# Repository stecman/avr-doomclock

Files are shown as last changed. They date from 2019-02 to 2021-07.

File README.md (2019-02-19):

# Tiny GPS Clock

This is a `hh:mm:ss` clock that runs from the time contained in NMEA RMC sentences.
The code is targeted at an Atmel ATTiny13A.

Notes:

- As the target microcontroller doesn't have enough RAM to store a full NMEA sentence,
this project uses a custom parser that only reads RMC ("Recommended Minimum") sentences from a UART
and extracts the time from that (see`nmea.c`).

- The ATTiny13A lacks SPI and UART peripherals, so these are implemented in software.

Schematic and construction details can be found on [this project's hackaday.io page](https://hackaday.io/project/163826-gps-wall-clock).

## Building and flashing

The `avr-gcc` toolchain is required to build, but there are no other external dependencies.

```sh
# Build
make

# Flash with programmer configured in Makefile
make flash
```

## Testing

The simple test suite for NMEA RMC sentence decoding can be run manually with:

```sh
make test
```

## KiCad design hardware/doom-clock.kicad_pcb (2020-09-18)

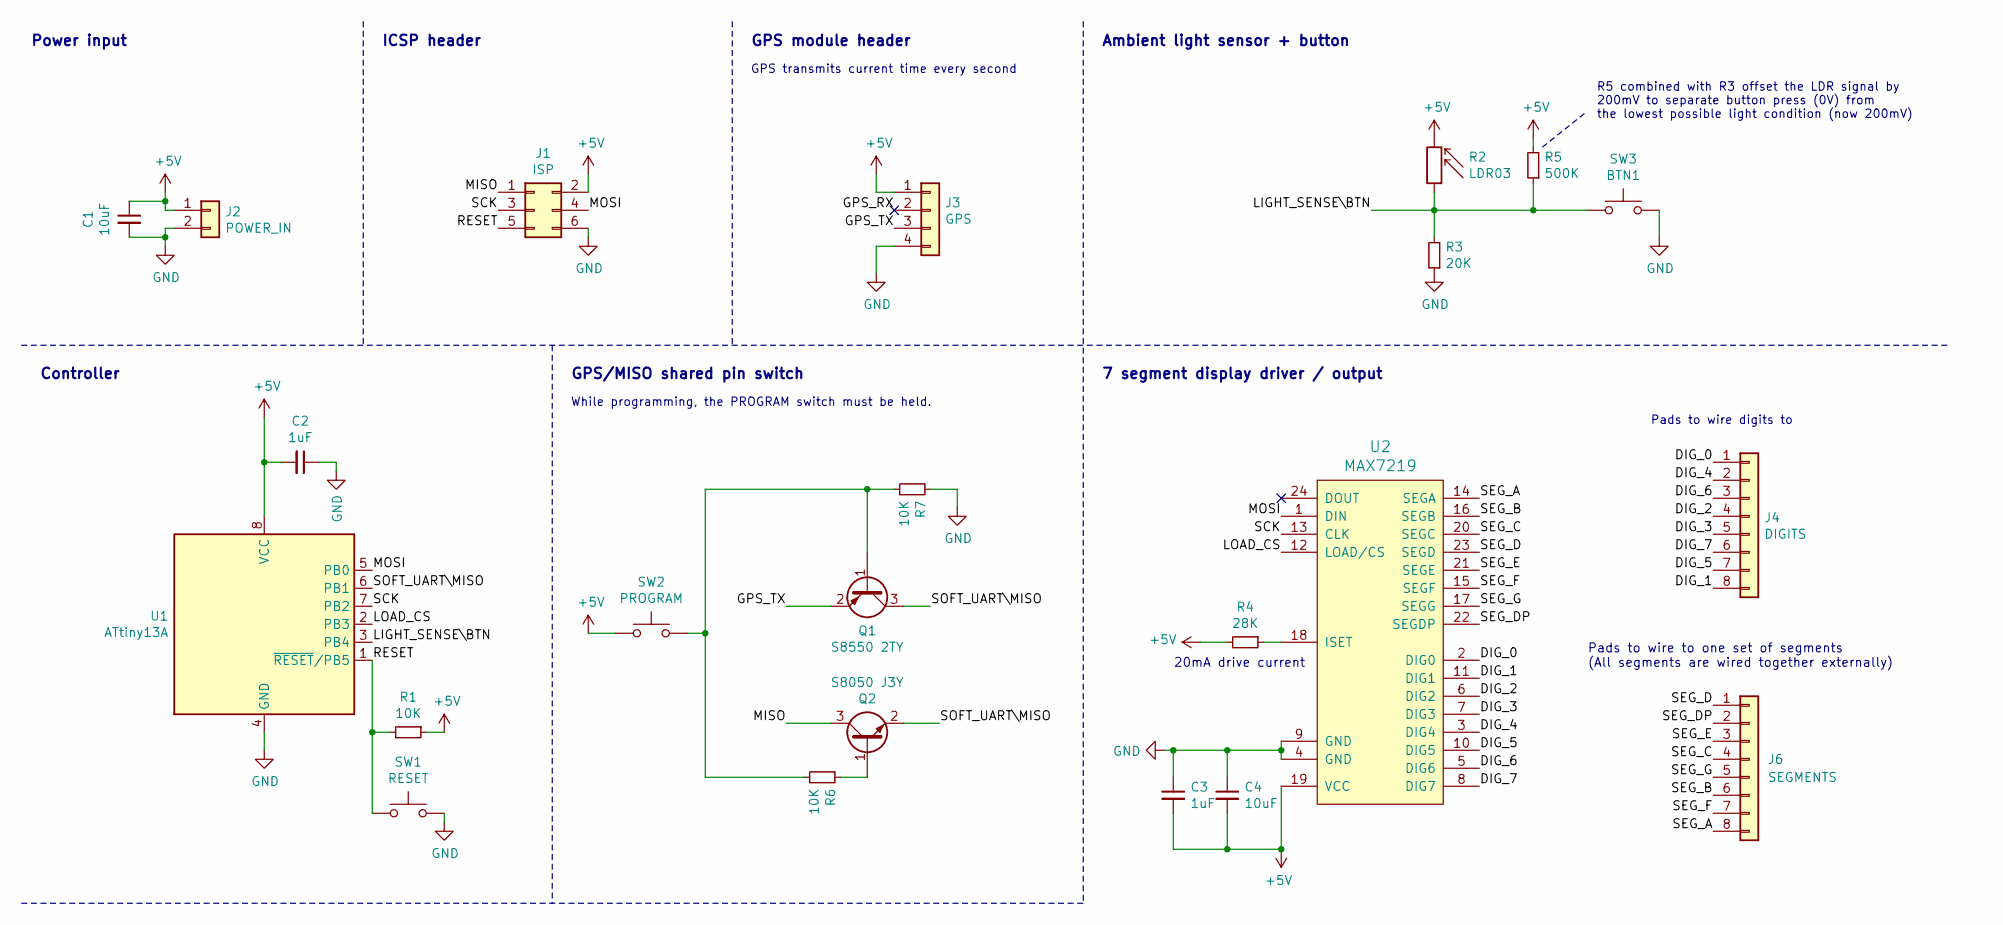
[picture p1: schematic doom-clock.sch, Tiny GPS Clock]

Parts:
C1, C4: 10uF; C_1206_3216Metric_Pad1.42x1.75mm_HandSolder
C2, C3: 1uF; C_1206_3216Metric_Pad1.42x1.75mm_HandSolder
J1: ISP; PinSocket_1x06_P1.27mm_Vertical
J2: POWER_IN; PinHeader_1x02_P2.54mm_Vertical
J3: GPS; PinHeader_1x04_P2.54mm_Vertical
J4: DIGITS; PinHeader_1x08_P2.54mm_Vertical
J6: SEGMENTS; PinSocket_1x08_P2.54mm_Vertical
Q1: S8550 2TY; SOT-23
Q2: S8050 J3Y; SOT-23
R1, R6, R7: 10K; R_1206_3216Metric_Pad1.42x1.75mm_HandSolder
R2: LDR03; R_LDR_5.2x5.2mm_P3.5mm_Horizontal
R3: 20K; R_1206_3216Metric_Pad1.42x1.75mm_HandSolder
R4: 28K; R_1206_3216Metric_Pad1.42x1.75mm_HandSolder
R5: 500K; R_1206_3216Metric_Pad1.42x1.75mm_HandSolder
SW1: RESET; SW_SPST_FSMSM
SW2: PROGRAM; SW_SPST_FSMSM
SW3: BTN1; SW_SPST_FSMSM
U1: ATtiny13A; SOIJ-8_SOIC-8
U2: MAX7219; SOP-24

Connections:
+5V: C1.1, C2.2, C3.2, C4.2, J1.2, J2.1, J3.1, R1.1, R2.2, R4.2, R5.2, SW2.1, U1.8 (VCC), U2.19 (VCC)
/DIG_0: J4.1, U2.2 (DIG0)
/DIG_1: J4.8, U2.11 (DIG1)
/DIG_2: J4.4, U2.6 (DIG2)
/DIG_3: J4.5, U2.7 (DIG3)
/DIG_4: J4.2, U2.3 (DIG4)
/DIG_5: J4.7, U2.10 (DIG5)
/DIG_6: J4.3, U2.5 (DIG6)
/DIG_7: J4.6, U2.8 (DIG7)
/GPS_TX: J3.3, Q1.2 (E)
/LIGHT_SENSE\BTN: R2.1, R3.2, R5.1, SW3.1, U1.3 (PB4)
/LOAD_CS: U1.2 (PB3), U2.12 (LOAD/CS)
/MISO: J1.1, Q2.3 (C)
/MOSI: J1.4, U1.5 (PB0), U2.1 (DIN)
/RESET: J1.5, R1.2, SW1.1, U1.1 (~RESET~/PB5)
/SCK: J1.3, U1.7 (PB2), U2.13 (CLK)
/SEG_A: J6.8, U2.14 (SEGA)
/SEG_B: J6.6, U2.16 (SEGB)
/SEG_C: J6.4, U2.20 (SEGC)
/SEG_D: J6.1, U2.23 (SEGD)
/SEG_DP: J6.2, U2.22 (SEGDP)
/SEG_E: J6.3, U2.21 (SEGE)
/SEG_F: J6.7, U2.15 (SEGF)
/SEG_G: J6.5, U2.17 (SEGG)
/SOFT_UART\MISO: Q1.3 (C), Q2.2 (E), U1.6 (PB1)
GND: C1.2, C2.1, C3.1, C4.1, J1.6, J2.2, J3.4, R3.1, R7.2, SW1.2, SW3.2, U1.4 (GND), U2.4 (GND), U2.9 (GND)
unnamed: Q1.1 (B), R6.1, R7.1, SW2.2
unnamed: Q2.1 (B), R6.2
unnamed: R4.1, U2.18 (ISET)

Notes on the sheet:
20mA drive current
Pads to wire to one set of segments (All segments are wired together externally)
Power input
ICSP header
Controller
GPS module header
GPS/MISO shared pin switch
Ambient light sensor + button
7 segment display driver / output
R5 combined with R3 offset the LDR signal by 200mV to separate button press (0V) from the lowest possible light condition (now 200mV)
While programming, the PROGRAM switch must be held.
GPS transmits current time every second
Pads to wire digits to

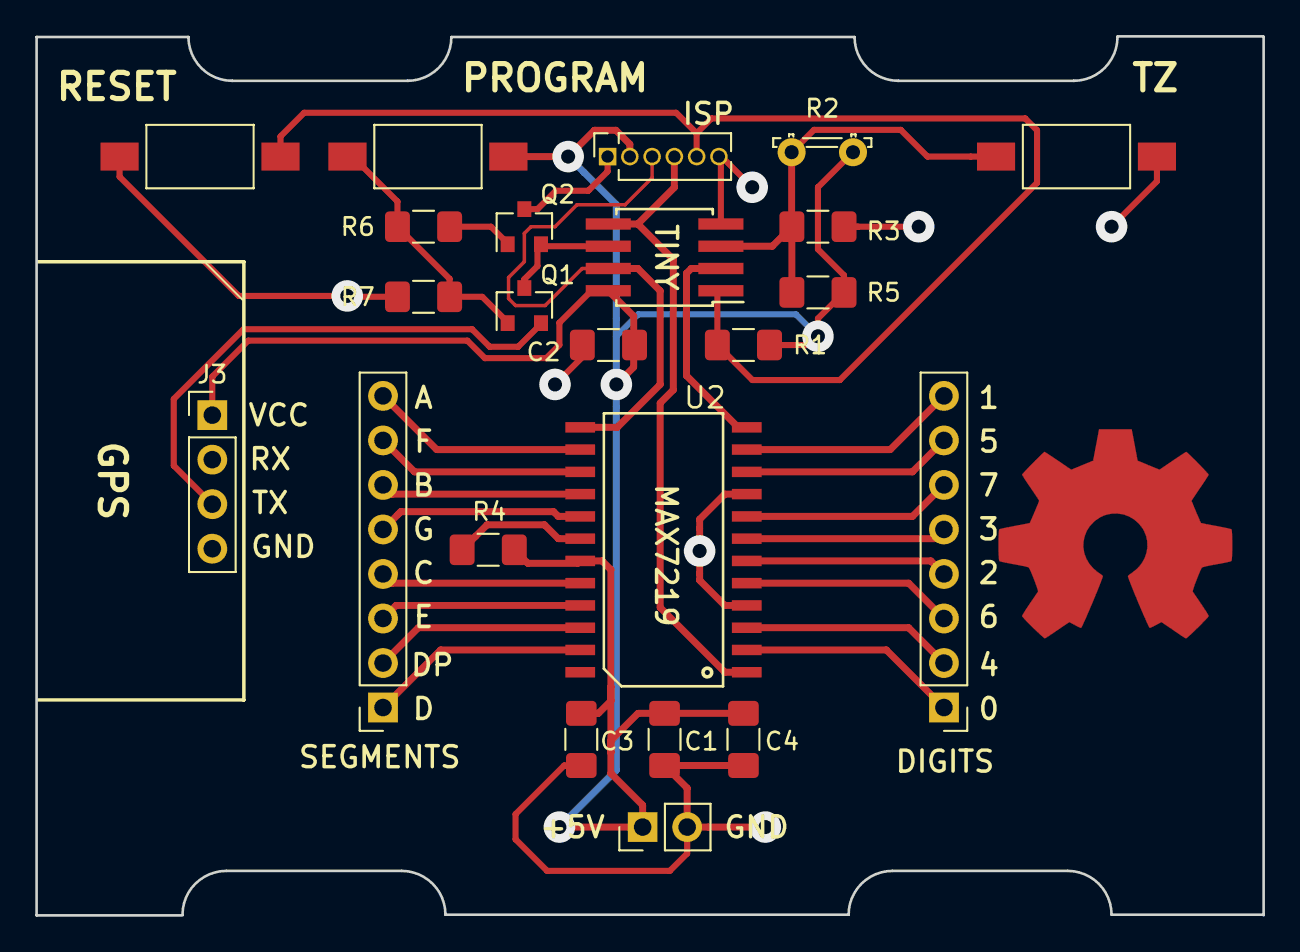
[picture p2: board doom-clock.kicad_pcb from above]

Board: 2 copper layers, 70.0 x 50.1 mm, 23 parts (0 on the bottom side), 29 nets.

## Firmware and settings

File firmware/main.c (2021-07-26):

#include <avr/io.h>
#include <avr/interrupt.h>
#include <util/delay.h>
#include <stdbool.h>

// Include sources directly so the compiler can optimise everything together
// This saves a significant amount of code space
#include "softuart.c"
#include "nmea.c"

#define PIN_MOSI PB0
#define PIN_SCK PB2
#define PIN_LOAD PB3
#define PIN_LIGHT_SENSE PB4

#define EEPROM_TIMEZONE_ADDR 0
#define kNumDigits 6

static int8_t _timezoneOffset = 0;
static GpsTime _gpsTime = {0, 0, 0};

static uint8_t _display_buf[kNumDigits];

static inline void setup_pins()
{
    // Load/CS pin is active low - initialise as high
    PORTB = _BV(PIN_LOAD);

    // MAX7219 pins as output
    // Soft UART and LDR are inputs by omission
    DDRB = _BV(PIN_MOSI) | _BV(PIN_SCK) | _BV(PIN_LOAD);
}

static inline void setup_adc()
{
    // Select PB4 (PIN_LIGHT_SENSE) in the ADC multiplexer
    // Put the significant 8-bits in the upper register as we only want to read that
    ADMUX = _BV(MUX1) | _BV(ADLAR);

    // Enable free-running ADC conversions with largest prescaler
    ADCSRA = _BV(ADATE) | _BV(ADEN) | _BV(ADSC)
        | _BV(ADPS0) | _BV(ADPS1) | _BV(ADPS2);
}

static inline void setup_timer()
{
    // Run TIM0 with 1024 prescaler
    TCCR0B = _BV(CS00) | _BV(CS02);
}

__attribute__ ((unused))
static void eeprom_wait_for_write()
{
    while(EECR & (1<<EEPE));
}

static void unchecked_eeprom_write(uint8_t address, uint8_t data)
{
    // Note: this doesn't wait for completion of any previous write
    // This is a code size optimisation as we only write a single byte infrequently

    // Set Programming mode
    EECR = (0 << EEPM1) | (0 >> EEPM0);

    // Set up address and data registers
    EEARL = address;
    EEDR = data;

    // Write logical one to EEMPE
    EECR |= (1 << EEMPE);
    // Start eeprom write by setting EEPE
    EECR |= (1 << EEPE);
}

static uint8_t unchecked_eeprom_read(uint8_t address)
{
    // Note: this doesn't wait for completion of any previous write
    // This is a code size optimisation as we only read at start-up, before any writes

    // Set up address register
    EEARL = address;

    // Start eeprom read by writing EERE
    EECR |= (1 << EERE);

    // Return data from data register
    return EEDR;
}

/**
 * Clock out a command and data pair to the MAX7219 (SPI-like)
 */
static void spi_send_16(uint16_t value)
{
    // Clock out 8 bits, MSB first
    for (uint8_t i = 16; i != 0; --i) {
        // Bring the clock low
        PORTB &= ~_BV(PIN_SCK);

        // Set output to 0
        PORTB &= ~_BV(PIN_MOSI);

        // Set output to 1 if this bit is set
        if (value & 0x8000) {
            PORTB |= _BV(PIN_MOSI);
        }

        // Bring clock high to send bit
        PORTB |= _BV(PIN_SCK);

        // Next bit
        value <<= 1;
    }
}

/**
 * Write to a register on the MAX7219
 */
static void max7219_cmd(uint8_t address, uint8_t data)
{
    // Select chip (active low)
    PORTB &= ~_BV(PIN_LOAD);

    // Clock out address and data as a combined word for code size savings
    spi_send_16((address << 8) | data);

    // Pull chip select high to latch data
    PORTB |= _BV(PIN_LOAD);
}

/**
 * Configure the MAX7219 for use
 */
static void max7219_init()
{
    // Set scan mode to 6 digits
    max7219_cmd(0x0B, kNumDigits);

    // Disable test mode
    max7219_cmd(0x0F, 0);

    // Enable binary decode mode
    max7219_cmd(0x09, 0xFF);

    // Enable display
    max7219_cmd(0x0C, 1);
}

/**
 * Modify the passed time with the current timezone offset
 */
static void apply_timezone_offset(GpsTime* now)
{
    // Adjust hour for timezone
    int8_t hour = now->hour;
    hour += _timezoneOffset;

    if (hour > 23) {
        hour -= 24;
    } else if (hour < 0) {
        hour += 24;
    }

    now->hour = hour;
}


static inline void set_display_pending_flag()
{
    // Re-purpose an unused register for single instruction set/clear
    // The reset pin isn't used as I/O, so this changing its registers has no effect
    DDRB |= _BV(PB5);
}

static inline uint8_t is_display_pending()
{
    // See set_display_pending_flag for what's going on here
    return DDRB & _BV(PB5);
}

static inline void clear_display_pending_flag()
{
    // See set_display_pending_flag for what's going on here
    DDRB &= ~_BV(PB5);
}


static inline void set_timepulse_seen_flag()
{
    // Re-purpose an unused register for single instruction set/clear
    // This "input buffer disable register" bit isn't functional as PB0 is always an output
    DIDR0 |= _BV(AIN0D);
}

static inline uint8_t has_seen_timepulse()
{
    // See set_timepulse_seen_flag for what's going on here
    return DIDR0 & _BV(AIN0D);
}

static inline void clear_timepulse_seen_flag()
{
    // See set_timepulse_seen_flag for what's going on here
    DIDR0 &= ~_BV(AIN0D);
}


static inline void display_buffer_set(uint8_t index, uint8_t value)
{
    _display_buf[index] = value;
}

/**
 * Send the current time to the MAX7219 as 6 BCD digits
 */
static void display_buffer_update(GpsTime* now)
{
    // Send time to display
    uint8_t digit = 0;

    for (int8_t i = 0; i < 3; ++i) {

        // Manually digit into tens and ones columns
        // This saves 25 bytes vs. using the divide and modulo operators.
        uint8_t ones = ((uint8_t*) now)[i];
        uint8_t tens = 0;

        while (ones >= 10) {
            ones -= 10;
            ++tens;
        }

        display_buffer_set(digit++, tens);
        display_buffer_set(digit++, ones);
    }
}

static void display_buffer_send()
{
    for (int8_t i = kNumDigits; i != 0; --i) {
        // Send buffer values to 1-indexed digit addresses
        max7219_cmd(i, _display_buf[i-1]);
    }
}

/**
 * Set all digits on the display to a value with no illuminated segments
 */
static void display_clear()
{
    // Reverse loop to save an instruction as the order doesn't matter
    for (int8_t i = kNumDigits - 1; i >= 0; --i) {
        _display_buf[i] = 0x7F;
    }
}

static void display_no_signal()
{
    static uint8_t waitIndicator = 0;

    display_clear();

    // Turn on the decimal point on one digit
    display_buffer_set(waitIndicator, 0x8F);

    ++waitIndicator;
    if (waitIndicator == kNumDigits) {
        waitIndicator = 0;
    }
}

static void display_error_code(uint8_t code)
{
    display_clear();

    // Display error code
    display_buffer_set(0, 11 /* E */);
    display_buffer_set(1, code);
}

static void display_timezone()
{
    display_clear();

    uint8_t value;

    // Put sign of timezone in the hours column
    if (_timezoneOffset < 0) {
        display_buffer_set(1, 10 /* - */);
        value = _timezoneOffset * -1;
    } else {
        display_buffer_set(1, 14 /* P */);
        value = _timezoneOffset;
    }

    // Split value into tens and ones columns manually to save code size
    uint8_t ones = value;
    uint8_t tens = 0;

    while (ones >= 10) {
        ones -= 10;
        ++tens;
    }

    // Put number in the middle
    display_buffer_set(2, tens);
    display_buffer_set(3, ones);
}

static void increment_timezone()
{
    ++_timezoneOffset;

    if (_timezoneOffset > 13) {
        _timezoneOffset = -12;
    }
}

void increment_time(GpsTime* tim)
{
    ++tim->second;

    if (tim->second == 60) {
        tim->second = 0;
        ++tim->minute;
    }

    if (tim->minute == 60) {
        tim->minute = 0;
        ++tim->hour;
    }

    if (tim->hour == 24) {
        tim->hour = 0;
    }
}

static void restore_timezone()
{
    const int8_t timezone = unchecked_eeprom_read(EEPROM_TIMEZONE_ADDR);

    // Restore if the value read from eeprom looks like a timezone
    if (timezone >= -12 && timezone <= 13) {
        _timezoneOffset = timezone;
    }
}

static void display_adjust_brightness(const uint8_t reading)
{
    // Map of brightness (index) to minimum ADC reading to trigger
    // Note the 200mV offset reads as around 10 with this configuration
    static const __flash uint8_t brightnessTable[] = {
        30, // 9%  duty cycle
        40, // 15% duty cycle
        50, // 21% duty cycle
        65, // 28% duty cycle
        80, // 34% duty cycle
        95, // 40% duty cycle
        110, // 46% duty cycle
        125, // 53% duty cycle
        140, // 59% duty cycle
        155, // 65% duty cycle
        170, // 71% duty cycle
        185, // 78% duty cycle
        200, // 84% duty cycle
        215, // 90% duty cycle
        230, // 96% duty cycle
    };

    // State to obtain an average of LDR readings
    // The size of this array should  be a power of two
    static uint8_t averageBuffer[16] = {};
    static uint8_t writeIndex = 0;
    static uint16_t runningTotal = 0;

    // Adjust running total with the new value
    runningTotal -= averageBuffer[writeIndex];
    runningTotal += reading;

    // Append new reading
    averageBuffer[writeIndex] = reading;
    writeIndex = (writeIndex + 1) % sizeof(averageBuffer);

    const uint8_t average = runningTotal/sizeof(averageBuffer);

    uint8_t intensity = 0;
    while (intensity < sizeof(brightnessTable) && brightnessTable[intensity] < average) {
        ++intensity;
    }

    // Set brightness
    max7219_cmd(0x0A, intensity);
}

static bool wait_for_timepulse()
{
    // Switch LOAD/CS pin to input with pull-up
    // The timepulse signal is wired to pull this line low
    DDRB &= ~_BV(PIN_LOAD);

    // Clear pin change flag
    GIFR |= _BV(PCIF);

    // Wait for a UART or Timepulse to change - whichever comes first
    while ((GIFR & _BV(PCIF)) == 0);

    // Check if the timepulse caused the pin change flag
    bool is_timepulse = (PINB & _BV(PIN_LOAD)) == 0;

    // Set LOAD/CS back to output idling high
    DDRB |= _BV(PIN_LOAD);

    return is_timepulse;
}

static inline bool timer_has_overflowed()
{
    return TIFR0 & _BV(TOV0);
}

static inline void timer_reset_overflow()
{
    TIFR0 = 0xFF; // Clear all TIM0 interrupt flags
}

int main(void)
{
    // Flag state changes on the UART and Timepulse pins
    // Interrupts aren't used, but the interrupt flags are read
    PCMSK = _BV(PIN_SOFT_RX) | _BV(PIN_LOAD);

    setup_pins();
    setup_adc();
    setup_timer();

    max7219_init();

    restore_timezone();

    while (true) {

        // Update brightness if the timer has overflowed
        if (timer_has_overflowed()) {
            timer_reset_overflow();

            const uint8_t reading = ADCH;
            uint8_t numReads = 0;

            // The 200mV offset prevents the LDR output dropping below around 10 in an 8-bit reading
            // When the button is pressed the reading should drop to zero.
            const uint8_t buttonThreshold = 8;

            if (reading < buttonThreshold) {
                const int8_t oldTimezone = _timezoneOffset;

                while (ADCH < buttonThreshold) {
                    ++numReads;

                    // Require the reading to stay below the threshold for a series of readings
                    // (During real world use the ADC reading was occasionally dipping below the
                    // threshold without a button press, causing the timezone to increment unexpectedly.
                    if (numReads <= 15) {
                        while (!timer_has_overflowed()); // Delay for ~27ms
                        timer_reset_overflow();
                        continue;
                    }

                    // Reset period counter
                    numReads = 0;

                    // Update timezone
                    increment_timezone();
                    display_timezone();
                    display_buffer_send();
                }

                // Persist the timezone if it was changed
                if (oldTimezone != _timezoneOffset) {
                    unchecked_eeprom_write(EEPROM_TIMEZONE_ADDR, _timezoneOffset);
                }

            } else {
                // Update the display brightness for the ambient light level
                display_adjust_brightness(reading);
            }
        }

        // Wait for timepulse or UART message
        if (wait_for_timepulse()) {
            // Saw a timepulse signal - update the display immediately
            display_buffer_send();

            set_timepulse_seen_flag();
            clear_display_pending_flag();
        }

        // Wait for a line of text from the GPS unit
        GpsReadStatus status = gps_read_time(&_gpsTime);

        // Handle the processed message from the GPS module
        // This is done last as it blocks to sync with the timepulse signal
        switch (status) {
            case kGPS_Success: {

                // Update the display with the new parsed time
                apply_timezone_offset(&_gpsTime);

                if (is_display_pending()) {
                    // Display was pending but we saw another RMC message
                    // This means a timepulse was expected but didn't happen
                    clear_timepulse_seen_flag();
                    clear_display_pending_flag();
                }

                if (has_seen_timepulse()) {
                    // If preparing the display for the next second, the time needs to be incremented
                    increment_time(&_gpsTime);
                }

                display_buffer_update(&_gpsTime);

                if (has_seen_timepulse()) {
                    // Don't update the display yet - wait for the next timepulse
                    set_display_pending_flag();
                    continue;

                } else {

                    // Flag that display is not synced to timepulse by illuminating the last decimal point
                    _display_buf[kNumDigits - 1] |= 0x80;
                    break;
                }
            }

            case kGPS_NoMatch:
                // Ignore partial and unknown sentences
                continue;

            case kGPS_NoSignal:
                // Walk the decimal point across the display to indicate activity
                display_no_signal();
                break;

            case kGPS_InvalidChecksum:
                display_error_code(1);
                break;

            case kGPS_BadFormat:
                // This state is returned if the UART line isn't pulled high (ie. GPS unplugged)
                display_error_code(2);
                break;
        }

        // Push buffer to the display
        display_buffer_send();
    }
}

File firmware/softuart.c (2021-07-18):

#include "softuart.h"

#include <avr/io.h>
#include <util/delay.h>

// Number of microseconds for a 0.5 bit delay at the desired baud rate
// Calculated as ((1/BPS)/0.000001)/2
#define UART_DELAY_US 49 // ~9600 baud

/**
 * Read a single byte transmitted by the GPS
 */
AVRSTATIC uint8_t uart_read_byte()
{
    uint8_t data = 0x0;

    // Wait for line to go low (start bit)
    while ((PINB & _BV(PIN_SOFT_RX)) != 0);

    // 0.5 bit delay
    _delay_us(UART_DELAY_US);

    // Shift 8 data bits + 1 stop bit at the baud-rate determined by UART_DELAY_MS
    uint8_t bit = 9;
    do {
        --bit;

        // 1 bit delay
        _delay_us(UART_DELAY_US);
        _delay_us(UART_DELAY_US);

        // If this is the stop-bit, don't try to store the value
        if (bit == 0) {
            break;
        }

        // Shift to make room for next bit (reading most-significant bit first)
        data >>= 1;

        if ((PINB & _BV(PIN_SOFT_RX)) != 0) {
            data |= 0x80;
        }
    } while (bit != 0);

    return data;
}

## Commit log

2019-02-04 Fix digit decoding (late-night off math error)
    The display was counting to 11 instead of 10 ...37, 38, 39, 3-, 41, 42...
    [main.c]
2019-02-10 Fix wait indicator not wrapping at digit count
    [main.c]
2019-02-12 Add automatic display brightness based on ambient light level
    This adds code to read the LDR and set brightness smoothly. This may be completely
    overkill, but I'll see how it performs with real use. The problem could be solved
    with less program space using a single threshold with hysteresis to switch between
    "day" and "night" modes.
    I suspect flickering brightness might be an issue with this, which means it would
    need hysteresis anyway. With this chnage the code is now 966 bytes, so something
    might need to be compacted or removed to make room for the timezone button handling.
    [main.c]
2019-02-12 Make small optimisations to free a little program space
    This change-set takes the program size from 966 bytes to 920 bytes, freeing up
    just 4.4% of the total program space.
    - hex2int doesn't need to deal with lowercase characters. Forcing this loop
    to unroll saves 10 bytes. Clarified the code a little here too.
    - Removed null terminator from GPRMC string as it's not used (saves 2 bytes)
    - Removed initial brightness setting from max7219_init (saves 6 bytes):
    Intensity defaults to the minimum value on MAX721 power-up, which isn't a
    problem. Brightness is set correctly when `display_adjust_brightness() is
    eventually called.
    - Removed initial display_no_signal() call as the display w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
    [main.c]
2019-02-12 Reduce compiled size of uart_read_byte function by 18 bytes
    - Half-bit delay is now 49uS as this generates a fewer instructions for the
    configured clock frequency (no padding with nops)
    - Packed stopbit delay into loop to avoid two inlined _delay_us calls.
    This makes the size of this routine on-par with AVR ASM implementations
    I've seen around.
    [softuart.c]
2019-02-19 Improve the test output to abort on failure and use fancy colours
    This also adds a requirement for the tests to run successfully before the
    code will be flashed to a device.
    I really didn't need to do this, but it was a bit of fun.
2019-05-09 Fix negative timezone not handled correctly during display
    DateTime.hour is unsigned, so a negative timezone was displaying
    60-something instead of the correct adjusted hour.
    [main.c]
2019-05-09 Try to avoid timezone changing occassionally without button press
    The timezone has skipped forward 1-2 hours a few times in the last month.
    Something (maybe power glitches while it's already very dark) is causing
    the ADC reading to drop below the button-press threshold for one reading,
    which is advancing the timezone.
    This changes the logic to advance the timezone at the end of the 500ms
    period, requiring 5 readings 100ms apart to register as button presses.
    This should stop any momentary glitches in power or the ADC from causing
    an unwanted timezone change.
    [main.c]
2020-02-15 Reduce code size by 44 bytes to make room for timezone saving code
    This takes the compiled binary size from 994 to 950 bytes in preparation
    for adding code to persist the selected timezone in eeprom.
    Changes in order of most to least space saving:
    - Consolidated display clearing into a single function to save 30 bytes.
    Clearing was performed selectively in few different places which wasted
    quite a bit of code space. The refactored code ended up simpler as a bonus.
    - Dropped date parsing from the GPS decoding to save 14 bytes as
    day/month/year values aren't used in the firmware currently. This has
    been blocked out using an ifdef as the tests still parse dates and I
    didn't want to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
    [main.c]
2020-02-15 Move time mutation out of display_update() for grok-ability
    Coming back to this code after 9 months, I was irked by the display_update()
    mutating the time each call. This isn't technically a problem as the
    function is only called once after reading the time from the GPS, but
    it seems clearer to separate the application of timezone offset to the
    updating of digits on the display.
    This change doesn't affect binary size.
    [main.c]
2020-02-15 Store the last used timezone in eeprom and restore during power-on
    It's been bothering me that the clock doesn't remember its timezone as
    I've needed to unplug it a few times recently. I'm reluctant to unplug
    it currently as I need to take the clock off the wall each time to set
    the timezone again.
    [main.c]
2020-02-15 Fix timezone restored from eeprom typed as unsigned with bad comparison logic
    Fixes dumb late-night mistakes in the implementation
    [main.c]
2020-02-15 Free up an additional 8 bytes for saved timezone validation fix. This brings the code size from 1032 bytes in the previous commit to 1024 bytes (exactly 100% flash usage).
    [main.c]
2020-09-18 Add Kicad schematic and layout
    I'd recommend not using the layout included here as it's pretty gross.
    Best to create your own layout from the schematic.
    [doom-clock.kicad_pcb, doom-clock.sch]
2021-03-20 Add additional test for expected no signal case
2021-03-20 Remove redundant multiplication from manually unrolled loop
    This doesn't change the code size as GCC was smart enough to drop the
    redundant multiplication. Tidying this up for human readers in any case.
2021-07-17 Squeeze an additional 48 bytes of program space out of the existing code
    - Use a custom start-up implementation to remove redundant start-up code
    added by GCC to accommodate software resets (which never happen), free
    up space that was given to unused interrupt vectors. Also removes a few
    instructions related to the program exiting as this can't happen.
    This frees up 24 bytes for other code.
    - Combine MAX7219 command and data into a 16-bit value to be clocked out
    all at once. Saves 8 bytes.
    - Replace multiply by 10 with a bit-shift implementation. This stops the
    loop-based multiply function `__mulqi3` being linked. Saves 6 bytes.
    - Turned on generation of linker map file to all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
    [main.c]
2021-07-17 Change fuses to include EESAVE to preserve eeprom across flashing
2021-07-17 Change constants to defines to avoid warnings about losing const-ness
    [main.c]
2021-07-18 Replace AVR eeprom read/write functions to save 36 bytes program space
    This uses the EEPROM read and write implementations from the datasheet,
    but strips out waits for the previous write to complete. This check isn't
    needed as our reads only occur on start-up, and writes are at least a
    few seconds apart due to the way the timezone changing UI works.
    Defining these statically lets the compiler optimise further as these
    functions are only called once each.
    [main.c]
2021-07-18 Compile as a single unit to maximise compiler optimisation opportunities
    This saves 84 bytes in the current code at the cost of making the compiled
    assembly harder to follow as 85% of the program becomes a single function.
    Since space saving is the name of the game, this is a worthwhile compromise.
    Introduces a define AVRSTATIC so functions can be made static when
    compiling the firmware, and left as `auto` when compiling the test
    cases. If this ends up being annoying or confusing, the test cases can
    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
2021-07-18 Fix display intensity wrapping to 0x10 instead of maxing out at 0x0F
    The display brightness value was able to go to 16, which was interpreted
    by the MAX7219 as the lowest brightness (as it only looks at the low nibble).
    Fix this so it can go brighter than the number of brightness table entries.
    This didn't occur during normal use. I only noticed this when shining a
    bright light directly at the LDR while testing.
    [main.c]
2021-07-20 Wait until timepulse OR uart receive instead of only timepulse
    Timepulse isn't generated if the GPS doesn't have a match (by default -
    we probably don't have enough space to send config options). This effectively
    locks up the clock until a GPS fix is made
    [main.c]
2021-07-26 Fix display_clear() not clearing first digit (regression)
    [main.c]
2021-07-26 Fall back to displaying time as read while timepulse signal isn't firing
    Out of the box, the GPS module only generates a timepulse signal when it
    has a fix. We still want to display time in this state, but indicate that
    the display isn't synced to the timepulse.
    - Updated the main loop to detect if a timepulse is occurring and display
    the time accordingly.
    - Made the last decimal point illuminate if timepulse isn't being received.
    - Repurposed a couple of unused register memory bits for code size and
    ram savings, since the register memory allows for single-instruction
    bit set and clear operations
    - Changed brightness update to occur at most 30 times per second using TIM0
    - Changed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
    [main.c]
